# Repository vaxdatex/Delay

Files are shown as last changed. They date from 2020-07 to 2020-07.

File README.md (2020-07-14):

Erica Synths DIY Eurorack Modules
=================================

As Erica Synths discontinues its legacy DIY eurorack projects, we decided to make them open-source. We created Gerber files for PCB-made front panels and did slight changes in a module design in order to get rid of custom and rare components, still some modules require rare ICs which are available on www.ericasynths.lv. Each folder contains complete information and files to build a module: schematics, Gerber files for a front panel, Gerber files for PCBs, BOMs, component placement with values and designators and assembly manuals (please, note that some manuals are designed for older module versions).
By making these projects opensource, Erica Synths is ok, if the third parties use them for personal, educational or commercial purposes.
Erica Synths will not provide any support for these projects, please, refer to forums (www.muffwiggler.com) for information on build nuances, troubleshooting, part availability or alternatives.
 
Open-source projects are:

* [Bassline](https://www.ericasynths.lv/shop/diy/diy-kits-1/diy-bassline/) : all in one synth voice for acid basslines and drones.
* [BBD delay/flanger](https://www.ericasynths.lv/shop/diy/diy-kits-1/diy-bbd-delayflanger/) : all analogue effects unit based on V3205 BBD IC.
* [Delay](https://www.ericasynths.lv/shop/diy/diy-kits-1/diy-delay/) : tape and digital delay unit with tap tempo, tempo sync, reverse, hold and add functions.
* [Dual VCA](https://www.ericasynths.lv/shop/diy/diy-kits-1/diy-polivoks-vca-ii/) : Polivoks architecture inspired dual VCA, rare Russian differential opamps are now replaced with AS3360.
* [Envelope](https://www.ericasynths.lv/shop/diy/diy-kits-1/diy-polivoks-eg-ii/) : recreation of Polivoks envelope generator with loop and end of attack functions.
* [MIDI-CV](https://www.ericasynths.lv/shop/diy/diy-kits-1/diy-midi-cv-ii/) : Polivoks functionality inspired dual MIDI-CV converter with glide function.
* [Mixer](https://www.ericasynths.lv/shop/diy/diy-kits-1/diy-mixer-ii/) : simple 3 chanel audio mixer.
* [Modulator](https://www.ericasynths.lv/shop/diy/diy-kits-1/diy-modulator-ii/) : Polivoks functionality inspired LFO, noise and S&H module.
* [Output](https://www.ericasynths.lv/shop/diy/diy-kits-1/diy-output-ii/) : Output module with headphone amplifier.
* [Polivoks VCF](https://www.ericasynths.lv/shop/diy/diy-kits-1/diy-polivoks-vcf-ii/) : authentic recreation of the Polivoks VCF.
* [Swamp](https://www.ericasynths.lv/shop/diy/diy-kits-1/diy-swamp/) : our take of Wogglebug module with lots of unique extras.
* [VCO3](https://www.ericasynths.lv/shop/diy/diy-kits-1/diy-polivoks-vco-ii/) : Polivoks inspired VCO with nice extra – VCO Sync input.

License
=======

cc-by-sa-3.0

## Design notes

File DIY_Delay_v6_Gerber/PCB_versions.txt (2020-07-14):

2018. June. Componenets from Main placed on Controls board. Main discontinued.

Current versions:
Controls v6.0 June 2018
MCU v4.0 June 2018

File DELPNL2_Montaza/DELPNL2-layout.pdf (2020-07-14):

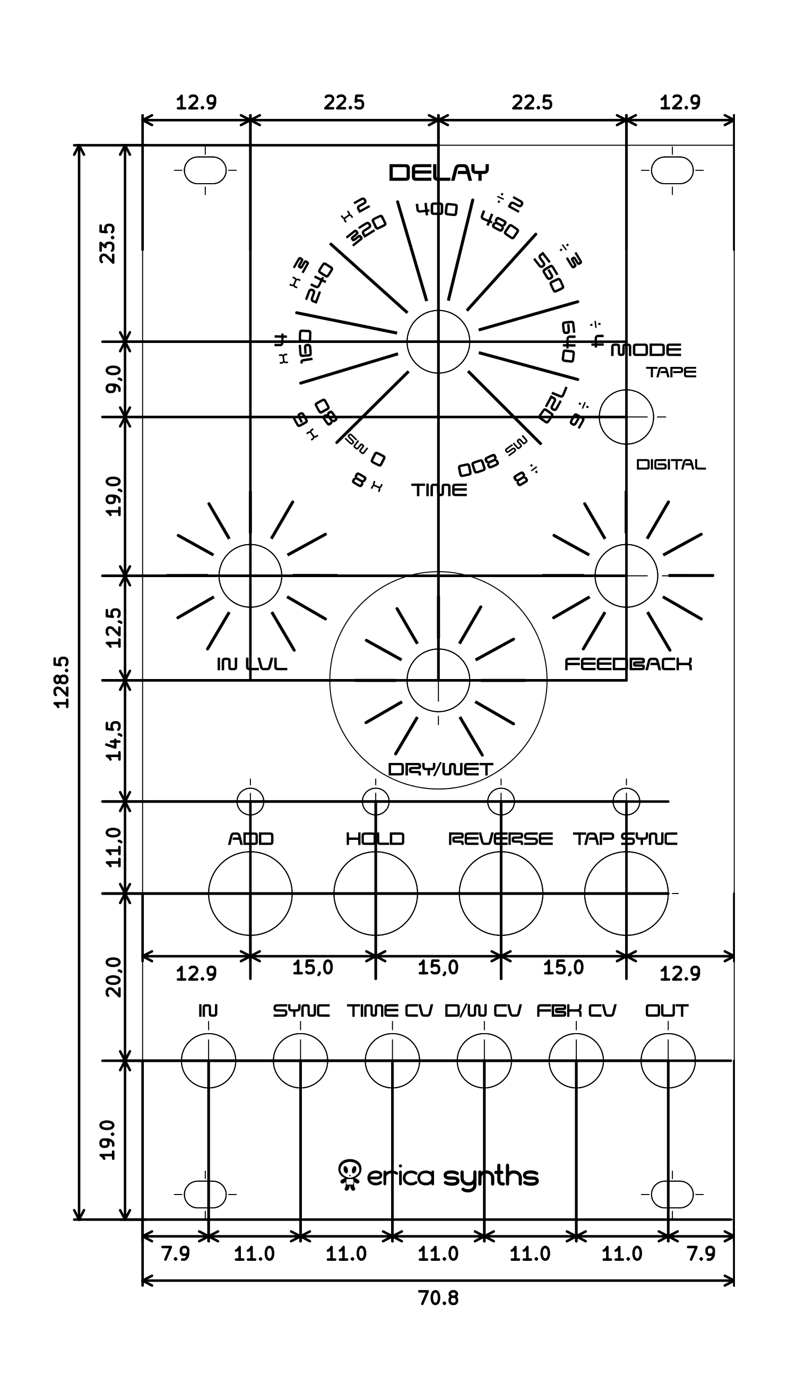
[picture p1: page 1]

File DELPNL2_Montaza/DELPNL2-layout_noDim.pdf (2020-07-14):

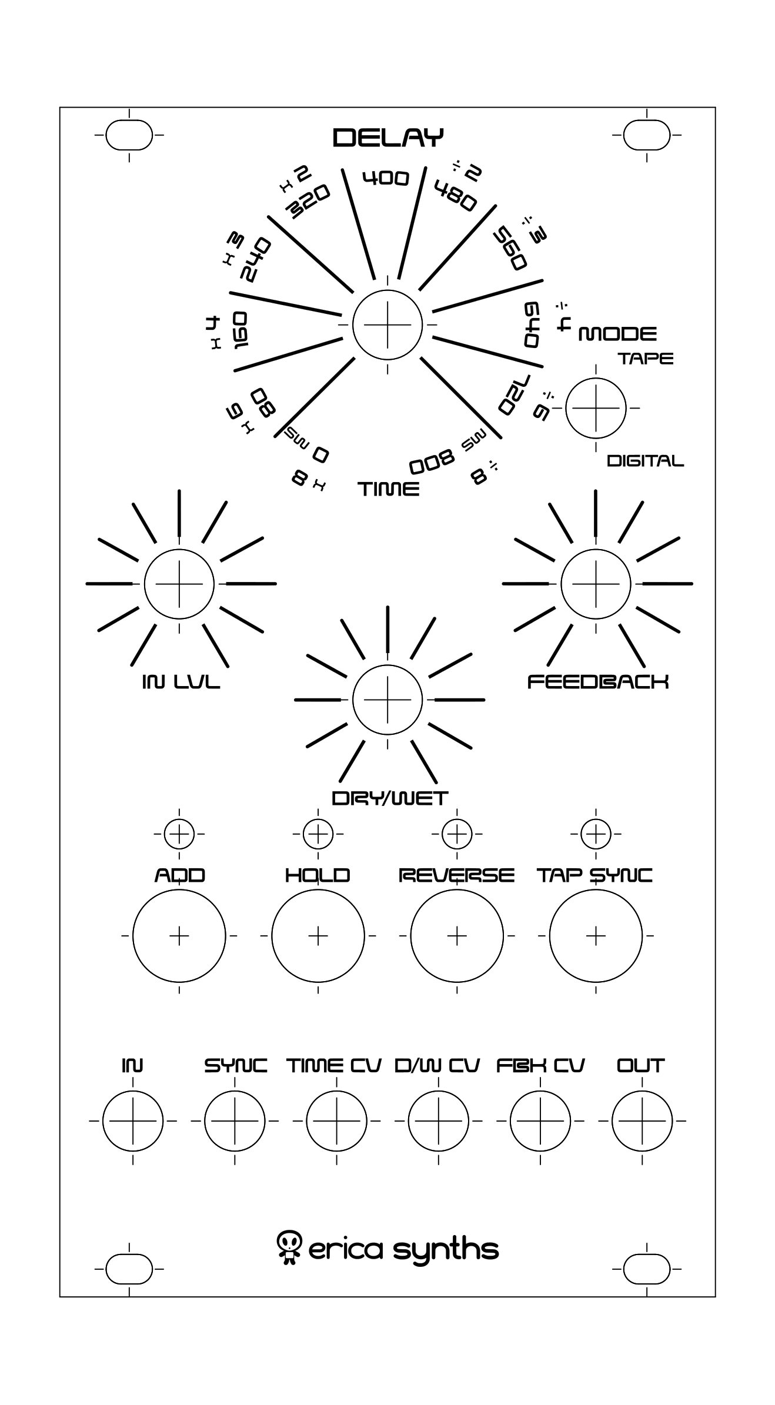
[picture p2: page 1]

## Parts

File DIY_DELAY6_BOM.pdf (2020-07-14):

### Erica Synths DIY DELAY v6.0 June 2018

Id Designator | Package | Quantity Designation | Supplier and ref
1 R107,R108 | RKT6V | 2 | 100R | single turn trimpot
| | | | (200R will work)

2

C1,C4,C5,C6,C7,C8,C9,C10,C11,C13,
C14,C15,C17,C19,C20,C23,C24,C26, C59,C61,C63,C64 | C-5mm | 22 | 0.1uF
3 C2,C3 | CE63x25 | 2 | 47uFx25V
4 C12 | C-5mm | 1 | 10nF
5 C16,C18 | C-5mm | 2 | 1uF
6 C28,C71 | CE63x25_NP | 2 | 22uFx16V | non polarized
7 C56,C57 | C-5mm | 2 | 470pF
8 C67,C68 | C-5mm | 2 | 100pF
9 C70 | C-5mm | 1 | 47pF
10 DA5,DA6,DA7 | DIP-14_Socket | 3 | TL074
11 DA16 | DIP-16_Socket | 1 | LM13700
12 L1,L2 | R0125W | 2 | 100uH | ferrite bead
13 R1,R3,R4 | RD901F | 3 | B100k | Alpha potentiometer
14 R2 | RD901F | 1 | A100k | Alpha potentiometer
15 R5,R12,R13,R23,R24,R29,R31,R33,
R45,R48,R84,R88,R118,R121,R145 | R_W4_THT | 15 | 100k
16 R6,R142,R143,R144 | R_W4_THT | 4 | 47k
17 R7,R9,R14,R15,R16,R32,R38,R39,R40 R_W4_THT | 9 | 10k
18 R11,R104,R106,R112,R114 | R_W4_THT | 5 | NU | not used
19 R17,R42,R44,R52 | R_W4_THT | 4 | 330R
20 R18,R102 | R_W4_THT | 2 | 1k
21 R22 | R_W4_THT | 1 | 130k
21 R83 | R_W4_THT | 1 | 140k
22 R65 | R_W4_THT | 1 | 100k
23 R86,R103,R105,R111,R113 | R_W4_THT | 5 | 470R
24 R90,R91 | R_W4_THT | 2 | 12k
25 R96,R97 | R_W4_THT | 2 | 2.2k
26 R98,R99,R117,R133 | R_W4_THT | 4 | 15k
27 R115,R119 | R_W4_THT | 2 | 24k
28 R136,R137 | R_W4_THT | 2 | 33k
29 SW1,SW2,SW3,SW4 | KS01-xxx | 4 | KS01-xxx
30 SW5 | 2MSxT1B5M2RE | 1 | 2MSxT1B5M2RE | SPDT ON-ON switch (https://www.thonk.co.uk/shop/sub-mini-toggle-switches/)
31 U1 | DIP-4_Socket | 1 | TLP781F | Optocoupler (http://uk.farnell.com/toshiba/tlp781f-d4-gb-f/optocoupler-tr-o-p-vde/dp/1684597)
32 VD2,VD5,VD7,VD9,VD18,VD25,VD29 | DO-35 | 7 | 1N4148
33 VD3,VD4 | DO-41 | 2 | 1N4001
34 VD11,VD19,VD20,VD21 | LED-3MM | 4 | LED-3mm | yellow
35 VD30 | TO-92 | 1 | LM4040/10V
36 VR1,VR2 | RB090-30 | 2 | ERF-RB-090-30 | Resettable fuse
37 VT1,VT2 | TO-92-M | 2 | 2N3904
38 VT8,VT9 | TO-92-M | 2 | NU | not used
39 VT10,VT11 | TO-92-M | 2 | 2N3906
40 XP1 | IDC-10MS | 1 | IDC-10MS
41 XS1,XS2,XS3,XS4,XS5,XS6 | WQP-PJ301M-12 | 6 | 3,5mm mono jacks Thonkiconn jacks (https://www.thonk.co.uk/shop/3-5mm-jacks/)
42 XS7,XS9 | PBS-8 | 2 | PBS-8_FEMALE | comes with a kit
43 XS8 | PBS-10 | 1 | PBS-10_FEMALE | comes with a kit
44 MCU | DDELMCU4 | 1 | MCU board | comes with a kit

Mouser shopping cart (excludes jacks, potentiometers and optocoupler) (https://www.mouser.com/ProjectManager/ProjectDetail.aspx?AccessID=2186d5c25a)

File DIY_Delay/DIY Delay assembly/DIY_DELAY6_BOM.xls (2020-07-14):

 | Erica Synths DIY DELAY v6.0 June 2018
Id | Designator | Package | Quantity | Designation
1 | R107,R108 | RKT6V | 2 | 100
2 | C1,C4,C5,C6,C7,C8,C9,C10,C11,C13,C14,C15,C17,C19,C20,C23,C24,C26,C59,C61,C63,C64 | C-5mm | 22 | 0.1uF
3 | C2,C3 | CE63x25 | 2 | 47uFx25V
4 | C12 | C-5mm | 1 | 10nF
5 | C16,C18 | C-5mm | 2 | 1uF
6 | C28,C71 | CE63x25_NP | 2 | 22uFx16V
7 | C56,C57 | C-5mm | 2 | 470pF
8 | C67,C68 | C-5mm | 2 | 100pF
9 | C70 | C-5mm | 1 | 47pF
10 | DA5,DA6,DA7 | DIP-14_Socket | 3 | TL074
11 | DA16 | DIP-16_Socket | 1 | LM13700
12 | L1,L2 | R0125W | 2 | 100uH
13 | R1,R3,R4 | RD901F | 3 | B100k | Thonk, Tayda
14 | R2 | RD901F | 1 | A100k | Thonk, Tayda
15 | R5,R12,R13,R23,R24,R29,R31,R33,R45,R48,R84,R88,R118,R121,R145 | R_W4_THT | 15 | 100k
16 | R6,R142,R143,R144 | R_W4_THT | 4 | 47k
17 | R7,R9,R14,R15,R16,R32,R38,R39,R40 | R_W4_THT | 9 | 10k
18 | R11,R104,R106,R112,R114 | R_W4_THT | 5 | NU
19 | R17,R42,R44,R52 | R_W4_THT | 4 | 330
20 | R18,R102 | R_W4_THT | 2 | 1k
21 | R22 | R_W4_THT | 1 | 130k
21 | R83 | R_W4_THT | 1 | 140k
22 | R65 | R_W4_THT | 1 | 100k
23 | R86,R103,R105,R111,R113 | R_W4_THT | 5 | 470
24 | R90,R91 | R_W4_THT | 2 | 12k
25 | R96,R97 | R_W4_THT | 2 | 2.2k
26 | R98,R99,R117,R133 | R_W4_THT | 4 | 15k
27 | R115,R119 | R_W4_THT | 2 | 24k
28 | R136,R137 | R_W4_THT | 2 | 33k
29 | SW1,SW2,SW3,SW4 | KS01-xxx | 4 | https://www.tme.eu/lv/details/ks01-bv-black/tastaturas-parsledzeji/highly/ks01-bv-bk/
30 | SW5 | 2MSxT1B5M2RE | 1 | 2MSxT1B5M2RE | Farnell
31 | U1 | DIP-4_Socket | 1 | TLP781F
32 | VD2,VD5,VD7,VD9,VD18,VD25,VD29 | DO-35 | 7 | 1N4148
33 | VD3,VD4 | DO-41 | 2 | 1N4001
34 | VD11,VD19,VD20,VD21 | LED-3MM | 4 | LED-3mm
35 | VD30 | TO-92 | 1 | LM4040/10V
36 | VR1,VR2 | RB090-30 | 2 | ERF-RB-090-30
37 | VT1,VT2 | TO-92-M | 2 | 2N3904
38 | VT8,VT9 | TO-92-M | 2 | NU
39 | VT10,VT11 | TO-92-M | 2 | 2N3906
40 | XP1 | IDC-10MS | 1 | IDC-10MS
41 | XS1,XS2,XS3,XS4,XS5,XS6 | WQP-PJ301M-12 | 6 | WQP-PJ301M-12 | Thonk
42 | XS7,XS9 | PBS-8 | 2 | PBS-8_FEMALE
43 | XS8 | PBS-10 | 1 | PBS-10_FEMALE
 | PPCB_DIY_DELAY6
 | DIY Delay MCU board - available from Erica Synths (http://www.ericasynths.lv/)

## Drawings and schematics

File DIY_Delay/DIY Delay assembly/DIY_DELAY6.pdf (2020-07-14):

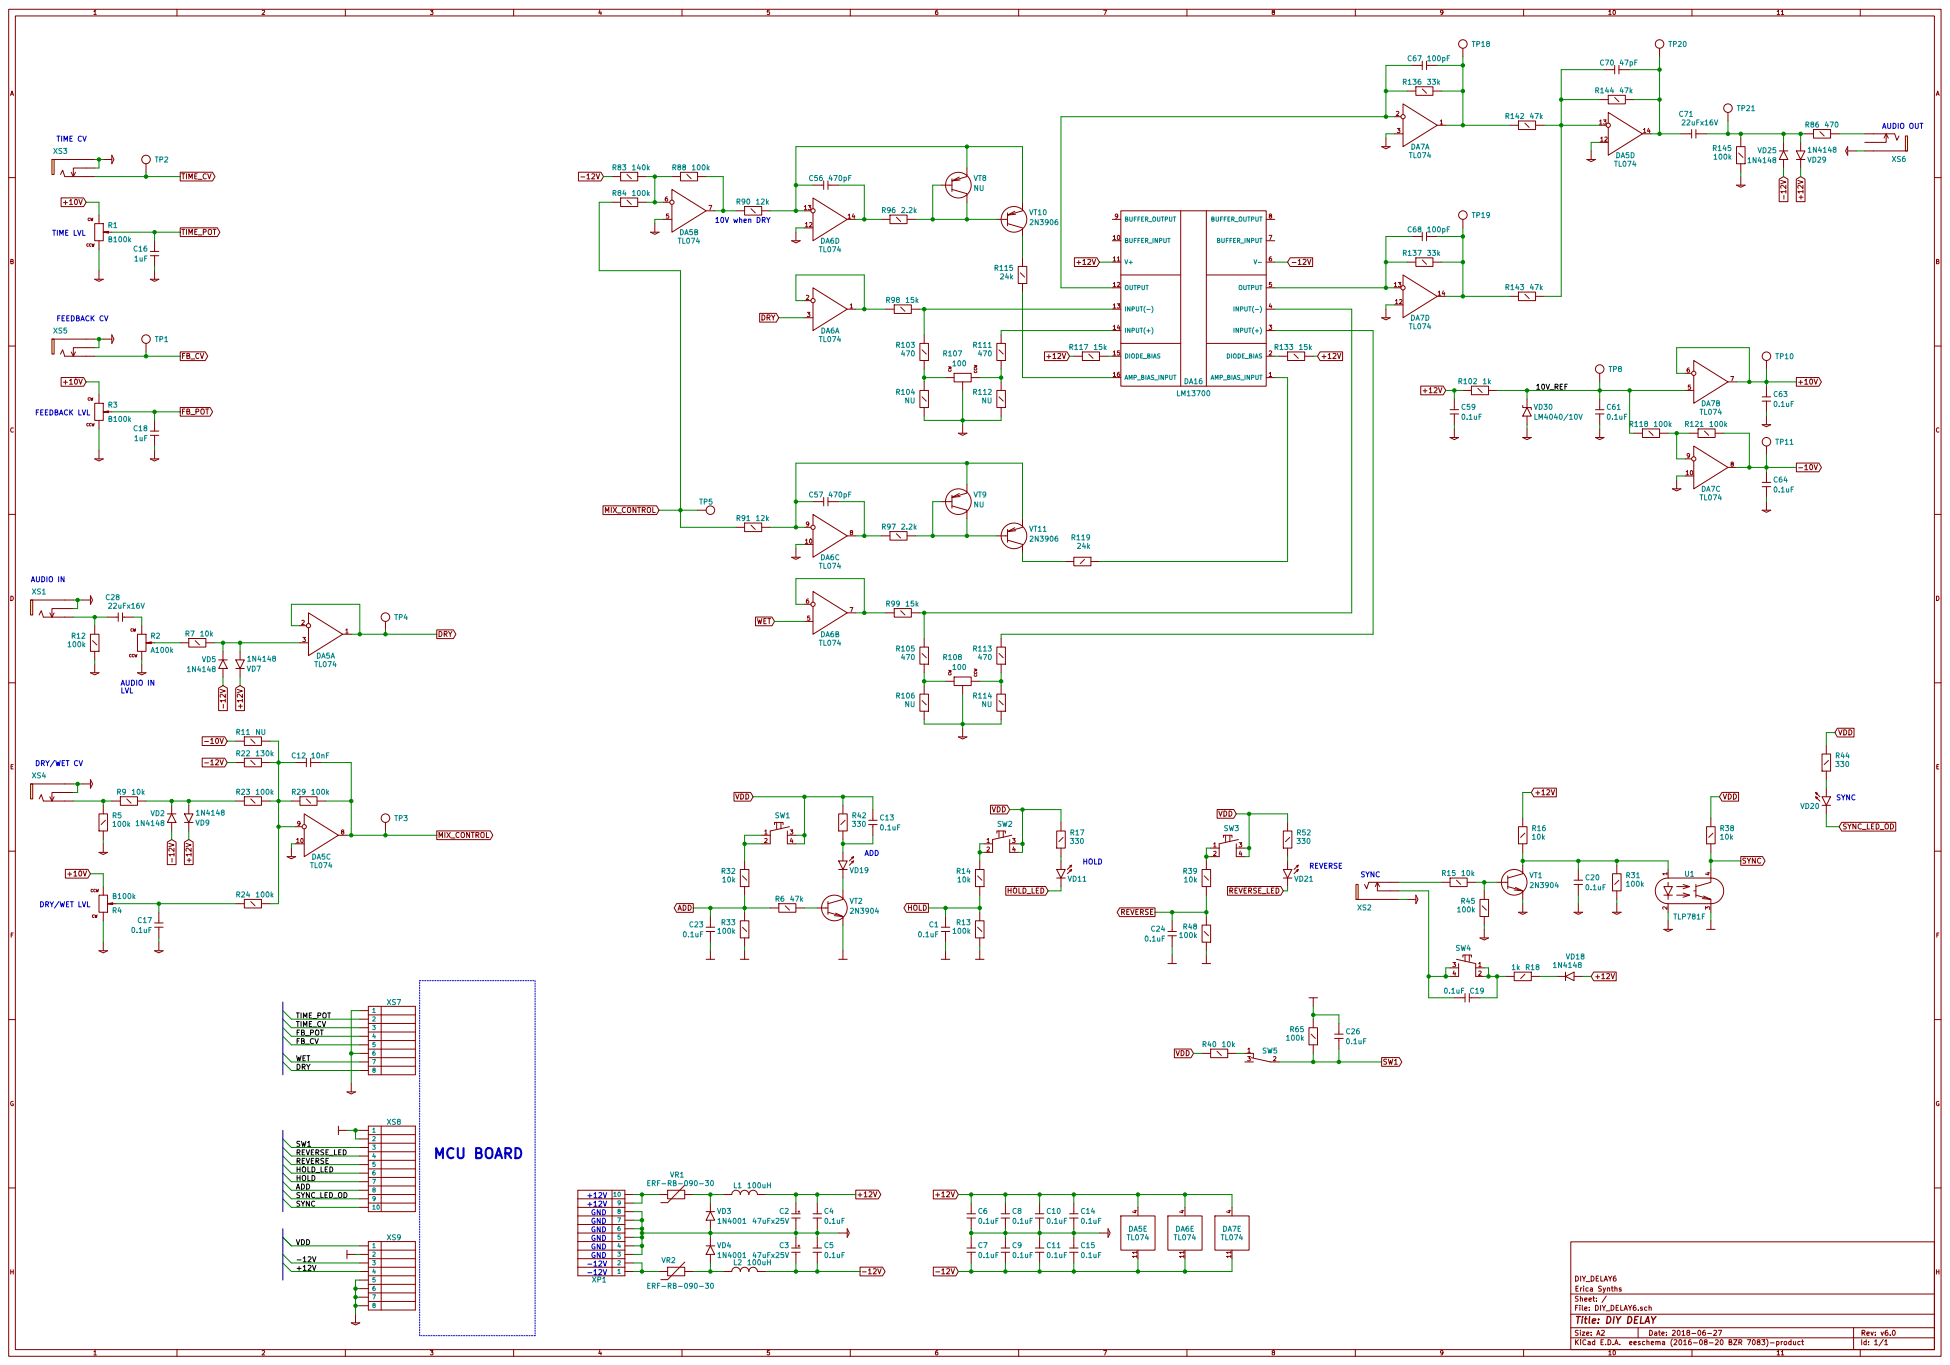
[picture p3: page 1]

8 3 | XS7

TIME_CV
FB_POT
FB_CV

10 3 | XS8

HOLD_LED
HOLD

GND | 10 XP1 +12V 7

GND | 6
GND | 5

DIY_DELAY6
File: DIY_DELAY6.sch Sheet: / Erica Synths

Id: 1/1 Title: DIY DELAY

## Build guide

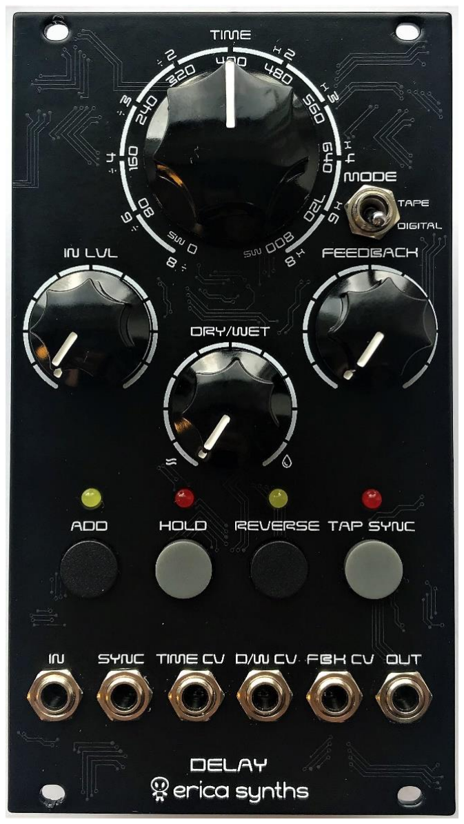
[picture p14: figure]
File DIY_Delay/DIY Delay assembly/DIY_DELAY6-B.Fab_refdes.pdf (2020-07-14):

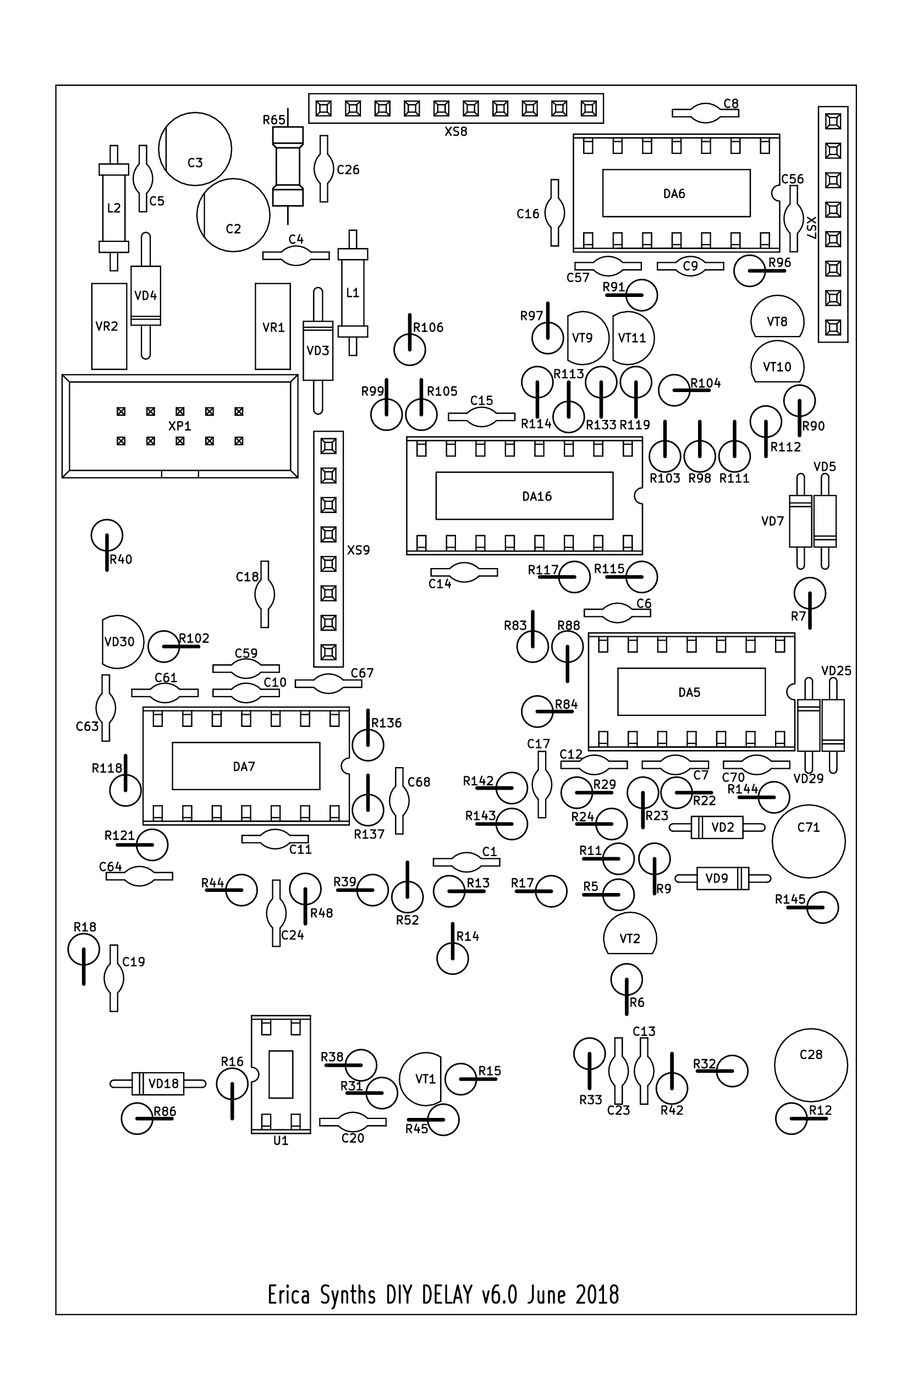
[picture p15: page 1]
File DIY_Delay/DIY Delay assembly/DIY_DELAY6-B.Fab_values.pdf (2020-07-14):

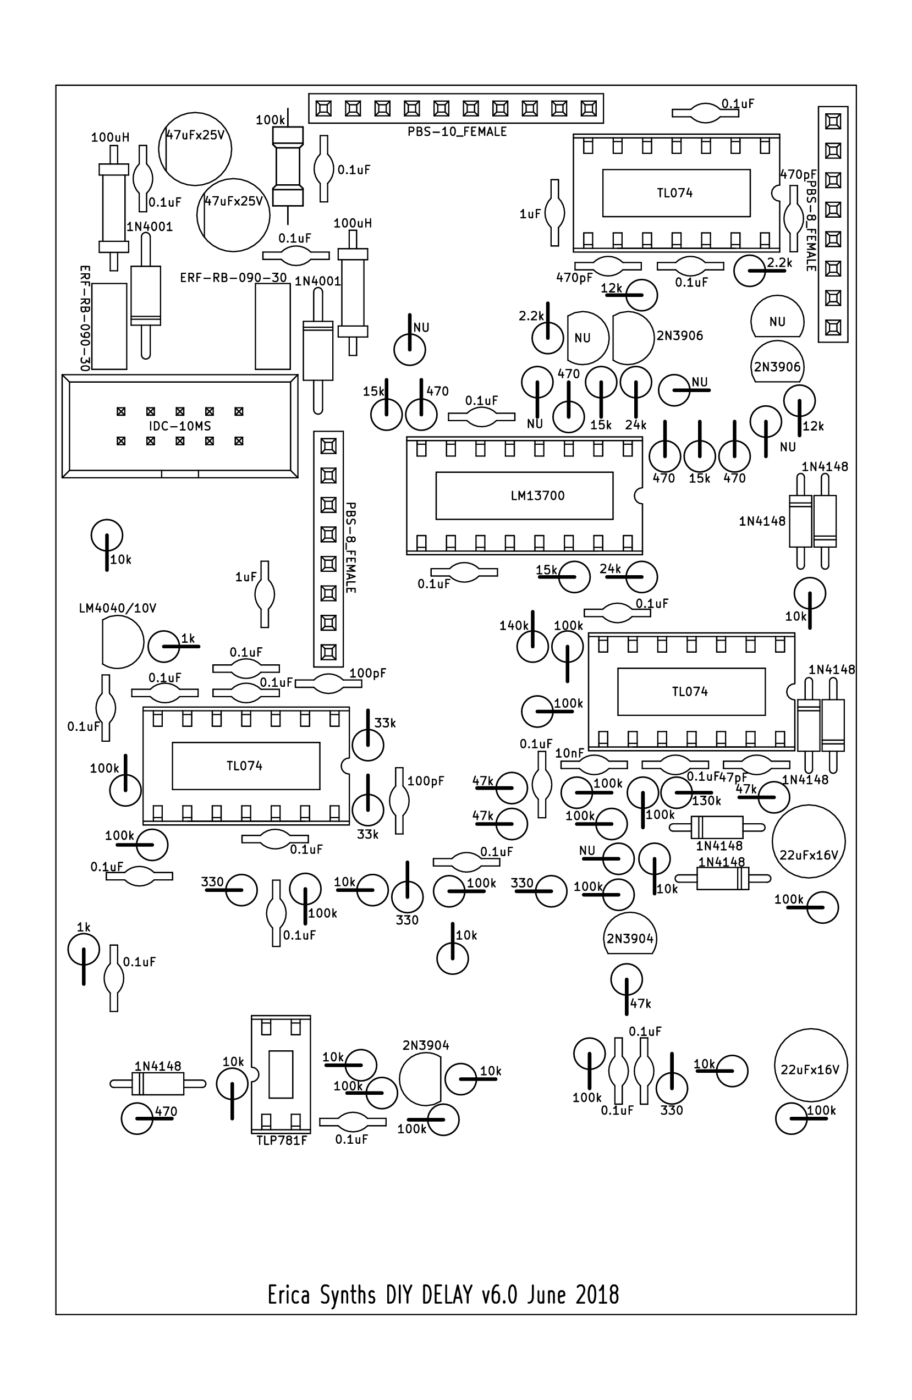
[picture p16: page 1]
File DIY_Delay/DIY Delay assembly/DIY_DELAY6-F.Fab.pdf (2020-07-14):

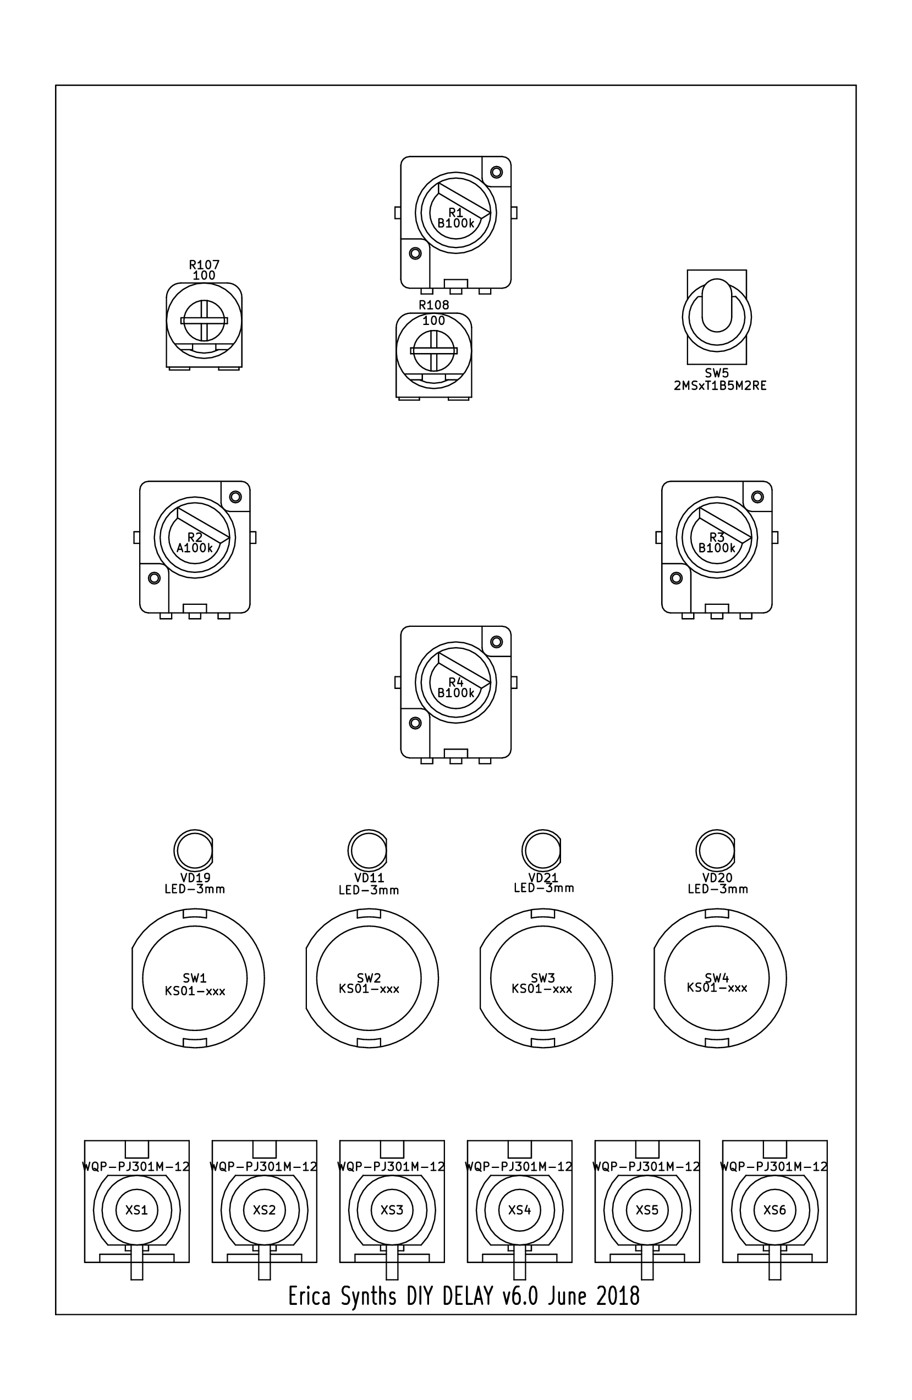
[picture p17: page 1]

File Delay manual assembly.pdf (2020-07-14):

## GUIDE TO ASSEMBLY OF ERICA SYNTHS DELAY MODULE

If you are reading this, most probably, you are about to build Erica Synths DIY DELAY module. The module is 45mm deep, skiff friendly, has solid mechanical construction and doesn’t require wiring. Erica Synths DIY Delay is hi-fi delay module with unique functionality typically found on advanced factory-produced units. We developed a custom DSP MCU board (comes pre-soldered and pre-programmed) and delay algorithms for syncable up to 800ms delays. Selectable Tape and Digital delay, BPM Sync, Tap Sync makes the module ideal for nuanced sound design. Furthermore Hold (freezes the sound up to 800ms), Add (adds several layers of sound on top) and Reverse (reverses sound in the hold buffer) functions allow to create crazy sonic artefacts.

The DIY Delay kit comes in three versions:
1) Set of 2 PCBs + MCU board,
2) Set of 2 PCBs + MCU board + mechanical parts (PCB connectors and spacer)+ panel,
3) Full kit.

FEATURES:
- Tape Delay and Digital Delay algorithms
- Up to 800ms delay time
- Syncable (clock and tap) delay time
- Delay time divisions and multiplications
- Freeze, Add and Reverse
- Manually and CV controlled delay time, feedback and dry/wet mix

SPECIFICATIONS:
- Max Delay time | 800ms
- Sampling frequency | 48khz 24bit
- Audio output amplitude | 10Vptp
- CV amplitude (full span) | -5V - +5V
- Panel width | 14HP
- Module depth | 45mm
- Power consumption | 97mA @+12V,
| 33mA@-12V

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
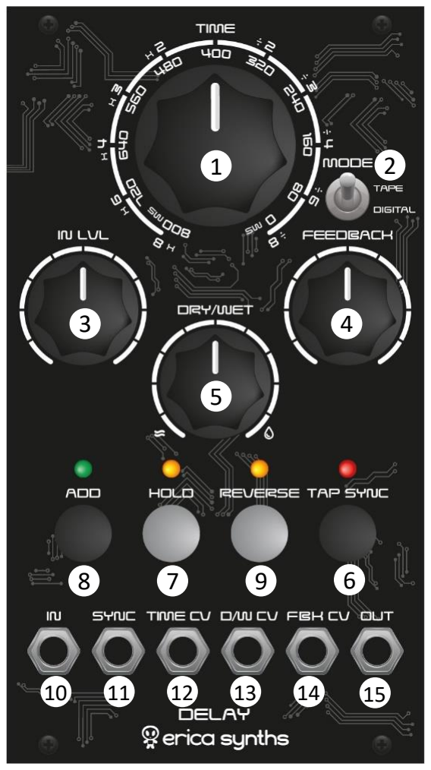
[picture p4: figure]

The big knob sets delay time from 0 CCW to 800ms CW. When in Sync mode (clock applied to SYNC input or you used TAP SYNC button), knob becomes delay time multiplier of divider. Please note that at low sync rates divider gets disabled, as the max delay time is 800ms.
Select the delay mode – Tape or Digital (no pitch shifting)

Adjust input level to avoid clipping

Use Tap Sync button to synchronize the delay time to the BPM. To exit sync mode push and hold the button for 2”
Push the Hold button to record an incoming signal in the module memory buffer. Record time depends on TIME setting, and it will start to loop the recorded buffer. To exit looping mode, push the HOLD button again. The LED will lit, when the hold mode is active When in Hold mode, you can push the ADD button to add more loops to the hold buffer
9

Hit the REVERSE button to reverse delayed signal. It also reverses all loops in the hold buffer
10 Patch audio signal here

11

This is SYNC input – the delay time will be synced to the incoming clock and you can divide and multiply delay time via TIME knob. To exit sync mode, push and hold the TAP SYNC button for 2”
12 This is delay time CV input
13 This is the Dry/Wet CV input that controls analogue crossfader
14 This is the Feedback CV input

15

Adjust feedback level! In full CW setting the module will go to self oscillation
Adjust Dry/Wet setting manually! This is full analogue circuit, and you also can control Dry/Wet via CV

This is the output of the module. We believe, you’ll enjoy results!

Take precautions with regard to electrostatic discharge (ESD) safety. Handling components should be done in electrostatically safe environment. Use personal and workplace grounding. Any discharge (even a minor one) from body to a component may permanently damage it.
Our PCBs have silkscreened both component values and designators, but as resistors are mounted vertically, we highly recommend you to print out files with component placement before you start assembly of the module. And, please, at least take a look on this manual!
Some components are marked as NU (not used) – leave those unpopulated! Some components are market as OPTION (those are for optional modifications) – leave those unpopulated for now.

### ASSEMBLY

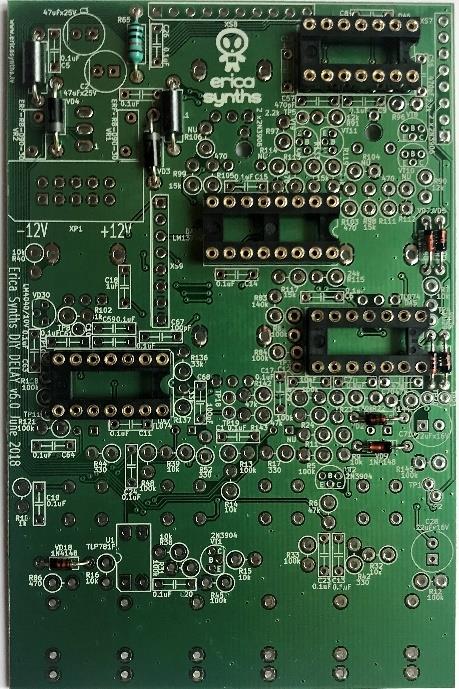
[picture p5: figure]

1

Solder horizontally placed resistors, diodes and
ferrite beads! Pay attention on orientation of diodes! Also, solder IC sockets!

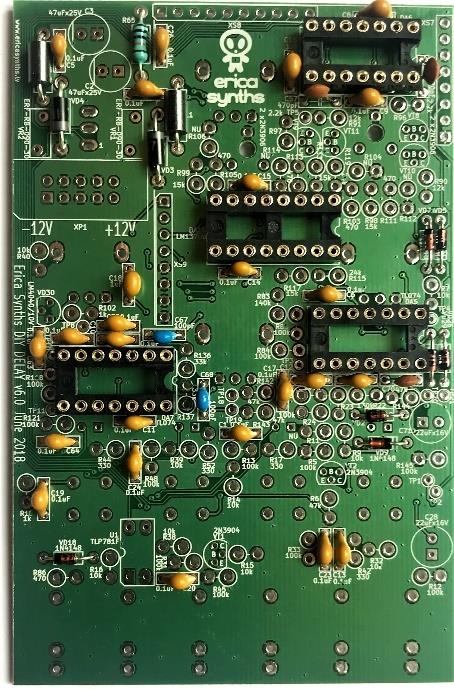
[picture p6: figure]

### 2 Solder ceramic capacitors!

3

Solder vertically placed resistors! Here it’s critically important to follow part placement as resistor density is quite high.

4

Solder electrolytic capacitors, transistors, voltage reference, resettable fuses and an optocoupler! Pay attention on correct orientation of the components!

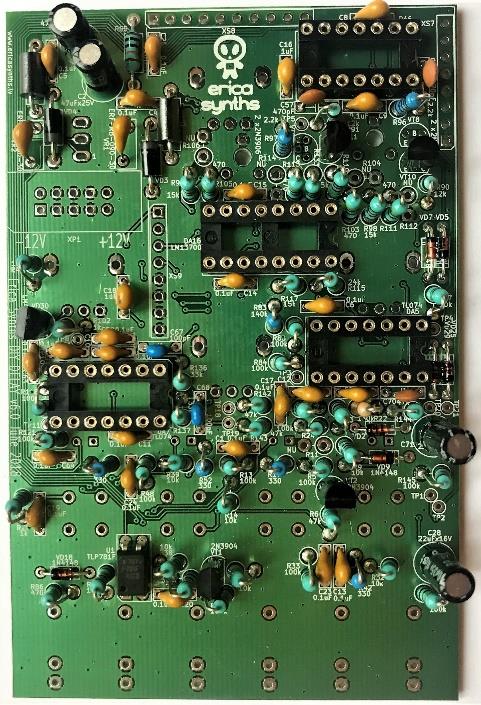
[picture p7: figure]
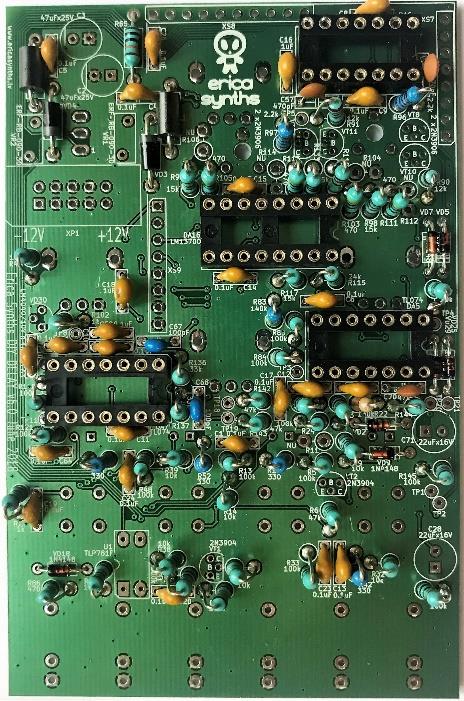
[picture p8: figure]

Negative lug of the
electrolytic
capacitor is marked
with a stripe!

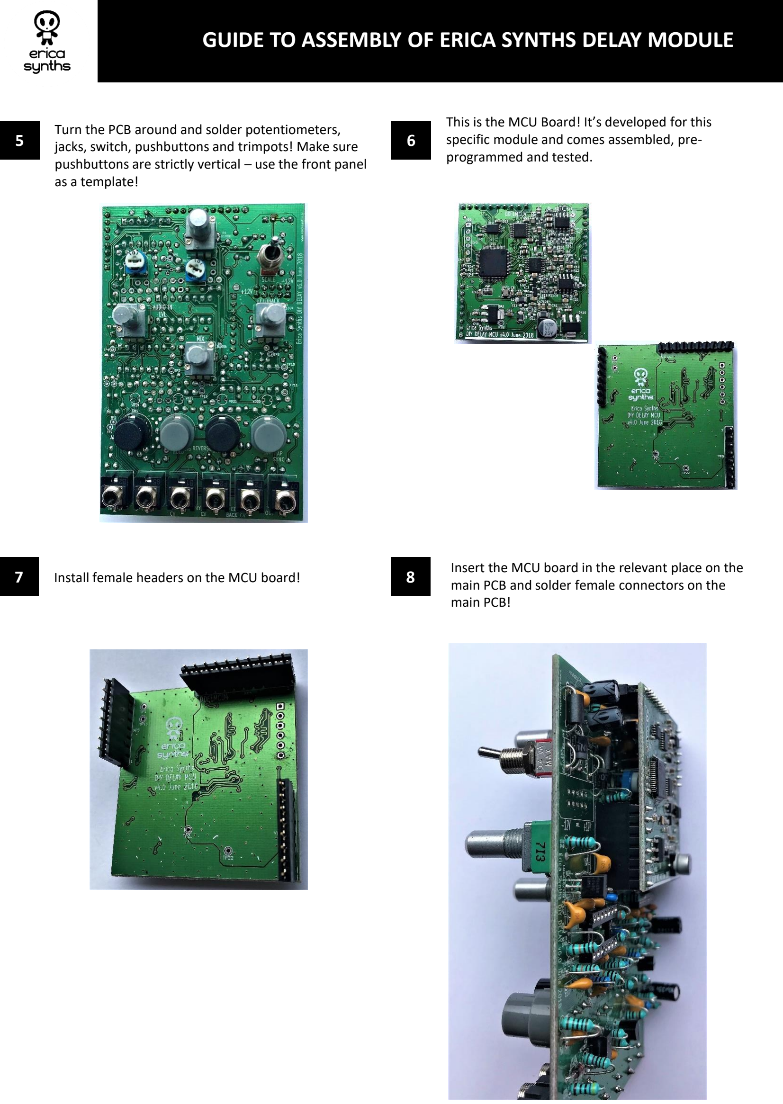
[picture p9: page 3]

5

Turn the PCB around and solder potentiometers, jacks, switch, pushbuttons and trimpots! Make sure pushbuttons are strictly vertical – use the front panel as a template!

6

This is the MCU Board! It’s developed for this specific module and comes assembled, pre-programmed and tested.

7 | Install female headers on the MCU board! | 8

Insert the MCU board in the relevant place on the main PCB and solder female connectors on the main PCB!

9

Remove the MCU board and solder PSU connector as shown on the picture below! Install ICs – pay close attention on the orientation of the ICs! When it’s done, insert the MCU board in its place.

10

Insert LEDs in relevant places! The anode (longer pin) should go into the square pad on the PCB! Do not solder LEDs yet!

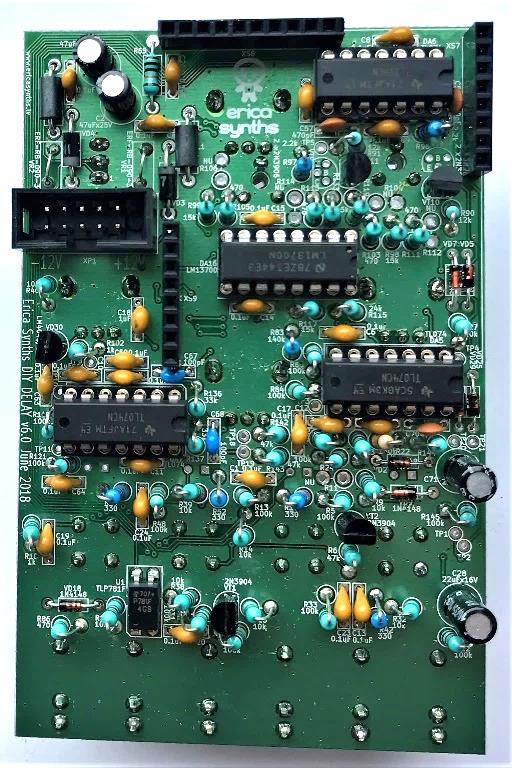
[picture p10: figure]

11 Install the front panel and fix it with few nuts. Place LEDs in the relevant holes and solder them! Now, remove the front panel and let’s perform a calibration!

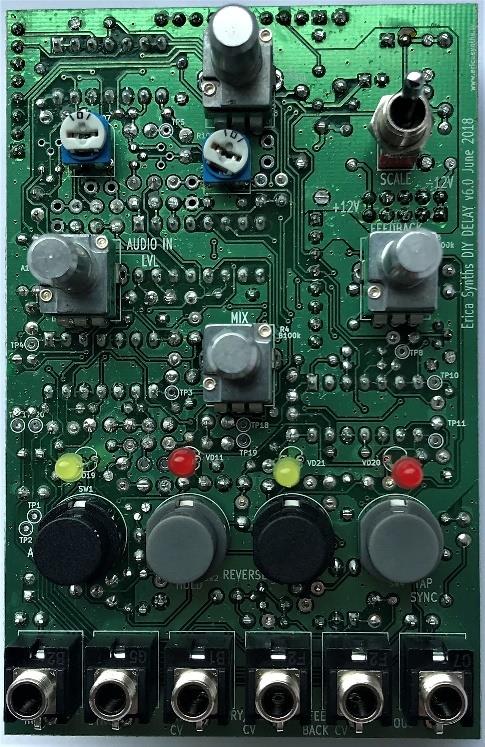
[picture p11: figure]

### 12 Connect the module to the PSU and connect some

sound source (snare drum or other sound with sharp VCA envelope will work the best)! Tweak knobs and make sure the module works! Push the HOLD button and check, if delayed sound starts to loop.
Now, let’s calibrate the Dry/Wet crossfader! Remove audio from the input, set IN LVL potentiometer all way CCW.
Set Dry/Wet knob all way CCW (Dry). Connect the voltmeter in DC measurement setting to the TP18 and adjust R107 until you get 0V on TP18.
Set Dry/Wet knob all way CW (Wet). Connect the voltmeter to the TP19 and adjust R108 until you get 0V on TP19.
Calibration complete!

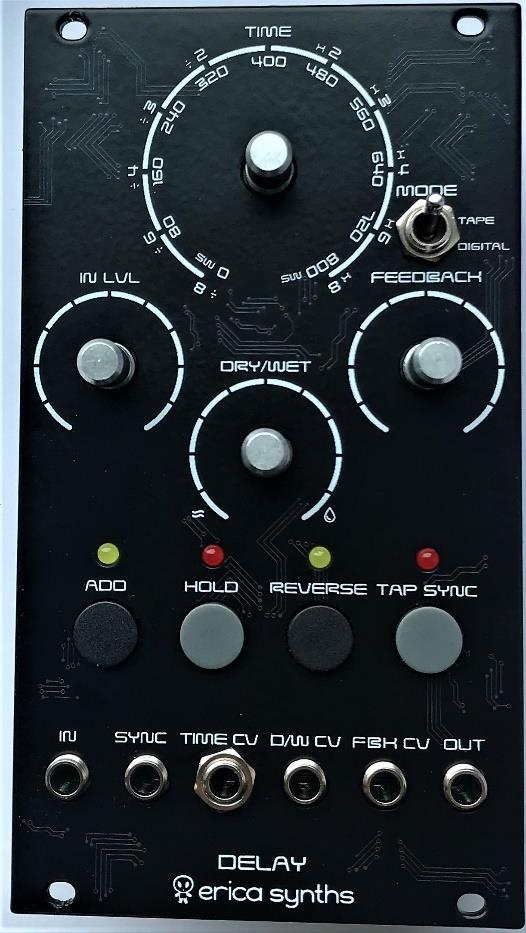
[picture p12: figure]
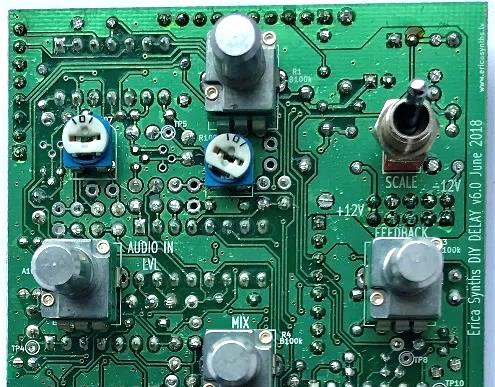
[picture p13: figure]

13

Install the front panel, fix it with potentiometer, jack and switch nuts! Install the potentiometer knobs! Congratulations! You have completed one of most advanced DIY Delay units in eurorack! Enjoy!
